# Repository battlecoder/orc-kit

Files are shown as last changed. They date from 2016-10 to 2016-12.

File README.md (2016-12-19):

# orc-kit
Open Source (and Hardware) Robotics Project.

Folder Content:
<ul>
<li><b>dist:</b> 3D models and vector patterns in "ready to use" formats (DXF and STL). Instructional sheet inside.</li>
<li><b>arduino:</b> Arduino libraries and example sketches for starters.</li>
<li><b>pcbs:</b> Eagle file and PNG render for the project custom circuit boards (Optional content)</li>
<li><b>vector-models:</b> "Source" files for the vector drawings and pieces (in SVG format)</li>
<li><b>3d pieces:</b> "Source" files for the 3D models (in SketchUp format)</li>
</ul>

For more information visit <a href="http://damnsoft.org/orc-kit">damnsoft.org/orc-kit</a>.

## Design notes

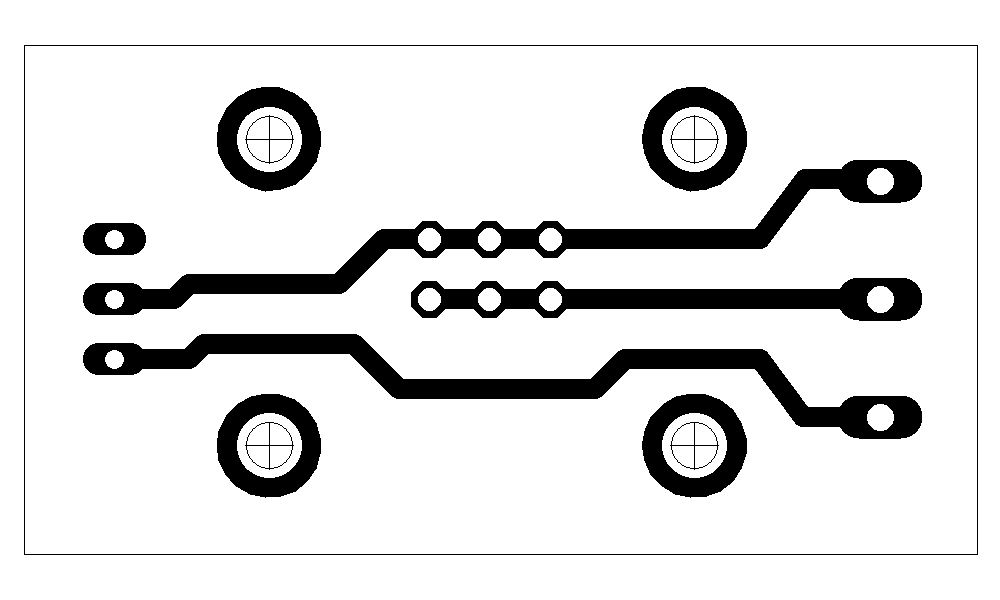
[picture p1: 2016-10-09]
pcbs/power_hub/power_hub.png

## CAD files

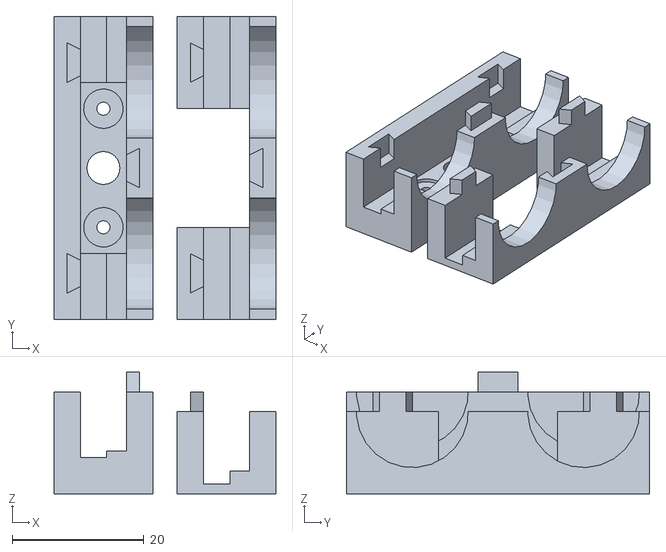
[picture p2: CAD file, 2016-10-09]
dist/3d pieces/ORC-KIT Sonar Mount (tight slanted tabs).stl
33.7 x 46.0 x 18.5

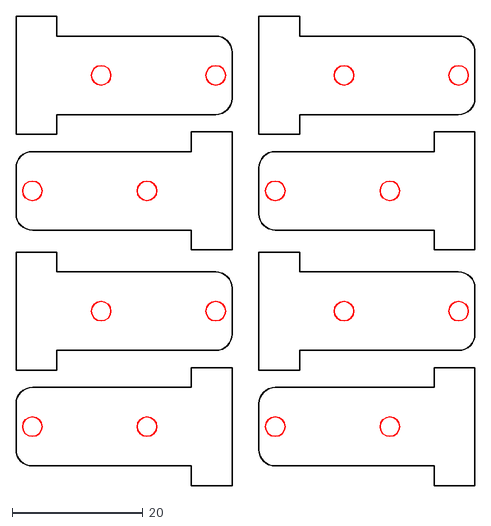
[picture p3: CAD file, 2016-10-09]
dist/lasercut/ORC-KIT Motor Mount set.dxf
70.1 x 71.6

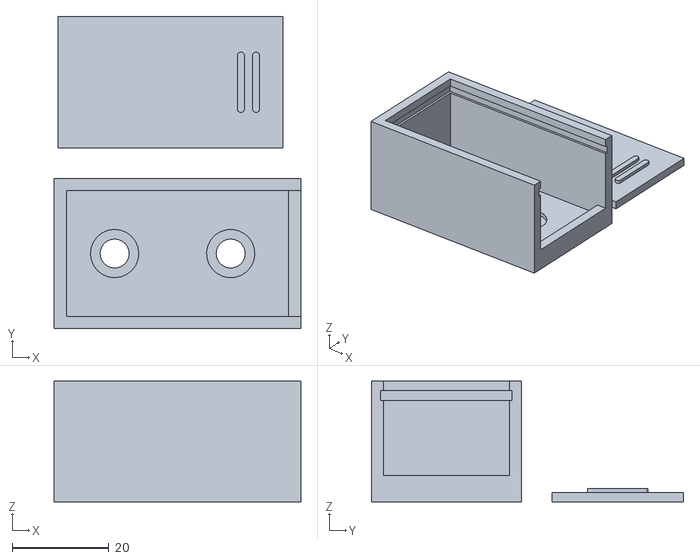
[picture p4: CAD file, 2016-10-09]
dist/3d pieces/ORC-KIT 9V Battery Holder.stl
51.0 x 64.5 x 25.0

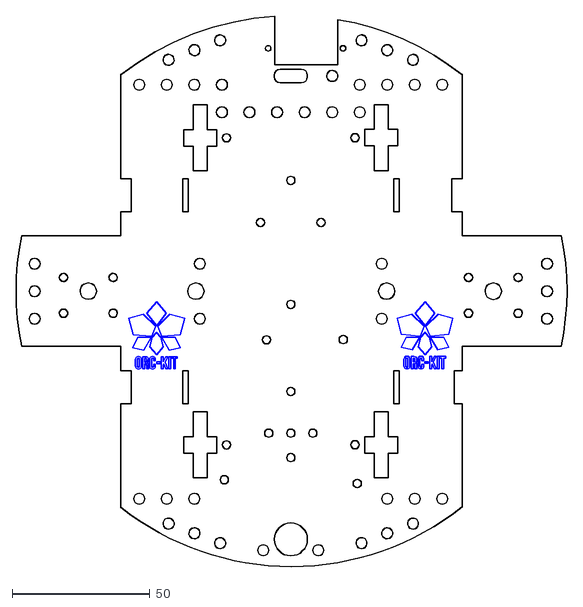
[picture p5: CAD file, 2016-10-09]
dist/lasercut/ORC-KIT Robot base.dxf
200.0 x 199.7

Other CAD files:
3d pieces/ORC-KIT 9V Battery Holder.skp
3d pieces/ORC-KIT Sonar Mount (tight slanted tabs).skp

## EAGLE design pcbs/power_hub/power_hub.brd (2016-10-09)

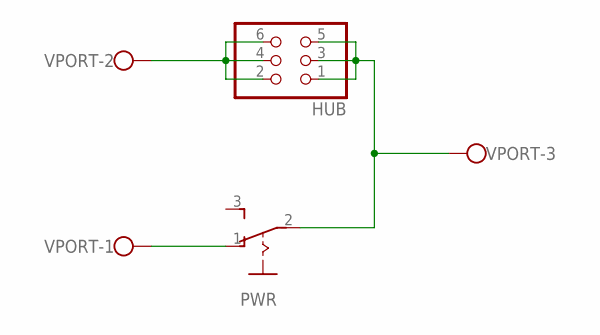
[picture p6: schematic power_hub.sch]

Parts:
HUB: PINHD-2X3; 2X03
PWR: M251
VPORT: W237-103

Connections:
unnamed: PWR.1 (O), VPORT.1
unnamed: HUB.1, HUB.3, HUB.5, PWR.2, VPORT.3
unnamed: HUB.2, HUB.4, HUB.6, VPORT.2

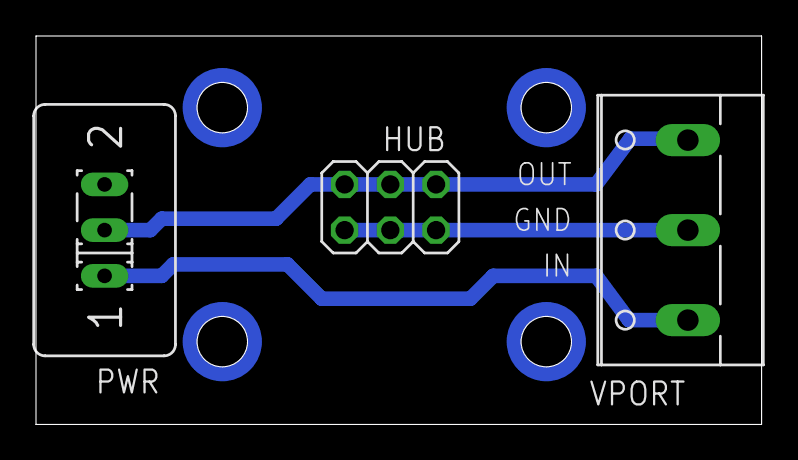
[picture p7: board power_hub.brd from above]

Board: 2 copper layers, 40.3 x 21.6 mm, 3 parts (0 on the bottom side), 3 nets.

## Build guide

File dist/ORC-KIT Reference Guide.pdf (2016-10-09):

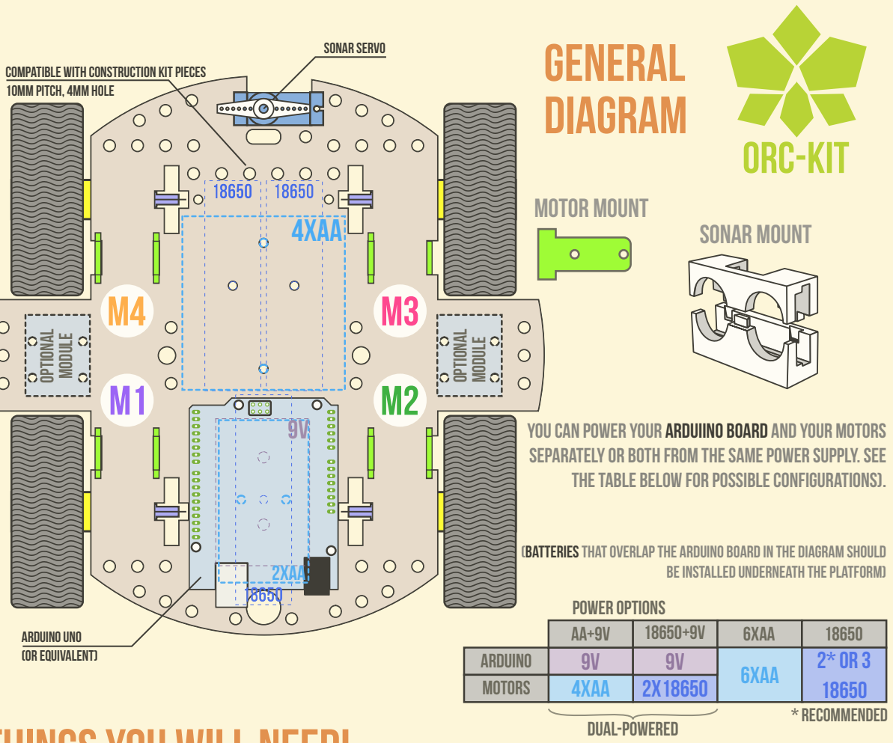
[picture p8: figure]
dual-powered; OPTIONAL; MODULE; Power OPTIONS; 6xAA; AA+9V 9V 4xAA; Arduino; Motors; * Recommended; 4xAA; 2xAA; GENERAL DIAGRAM; ARDuiNO UNO; (OR EQUIVALENT); sonar SERVO; COMPATIBLE WITH CONSTRUCTION kit pieces; 10MM PITCH, 4MM HOLE; Motor mount; BE INSTALLED UNDERNEATH THE PLATFORM); sonar mount

2016 orc-kit project by elias zacarias

1

2 12MM M2 SCREWS + BOLTS (FOR THE SONAR)

8 ORC-KIT MOTOR MOUNTS (ALSO LASER-CUT) OPTIONAL MODULE

FROM THE ORC-KIT PROJECT REPOSITORY

# things you will need!

STANDARD STUFF

1 ORC-KIT ROBOT BASE (LASER-CUT)

1 sonar mount (3d printed)
1 power hub board (optional. SEE PAGE 2)

1 ARDUINO UNO OR SIMILAR BOARD

4 HOBBY DC MOTORS WITH TIRES (THEY COME IN 48:1 AND 120:1 GEAR RATIOS)

1 ADAFRUIT MOTOR SHIELD OR 2X DUAL H-BRIDGES TO DRIVE THE MOTORS (*) 1 hc-sr04 or similar ultrasonic RANGEFINDER
1 sg90 MICROSERVO
BATTERIES & HOLDERS (DEPENDING ON YOUR CHOSEN power CONFIGURATION) PCB SPACERS/STANDOFFS AND THEIR RESPECTIVE M3 SCREWS AND BOLTs
1 hc-06 BLUETOOTH MODULE (optional. to be used with the bt control app!)

(*) the spots LABELED "OPTIONAL MODULE" IN THE DIAGRAM can hold in place TWO L9110S (OR SIMILAR) H-BRIDGES for shield-less builds. IF A DEDICATED ARDUINO SHIELD IS USED, HOWEVER, YOU CAN INSTALL SIMPLE CIRCUITS THERE, LIKE a BT/RADIO TRANSCEIVER, ORC KIT'S power hub, EXTRA SENSORS, ETC.

YOU CAN POWER YOUR ARDUIINO BOARD AND YOUR MOTORS SEPARATELY OR BOTH FROM THE SAME POWER SUPPLY. SEE THE TABLE below FOR POSSIBLE CONFIGURATIONS).

(BATTERIES THAT OVERLAP THE ARDUINO BOARD IN THE DIAGRAM SHOULD

1 TOGGLE switch (optional. not needed if using a power hub WITH SWITCH)

8 25MM (Or 30mm) m3 screws + boltS (for the motor MOUNTs)

1 orc-kit 9v battery holder (3d printed. required ONLY FOR dual power config.)

# construction process overview

SOLDER WIRES TO THE MOTORS AND INSTALL THEM UNDER THE BASE USING THE MOTOR MOUNTS.

WRITE AN ARDUINO SKETCH TO check THAT EVERYTHING WORKS!
(IF YOU USED THE COMPONENTS RECOMMENDED HERE YOU CAN USE THE SKETCHES FROM THE ORC-KIT PROJECT REPOSITORY)

Screw THE BATTERY HOLDERS REQUIRED BY YOUR SELECTED POWER CONFIGURATION IN PLACE.

INSTALL THE sonar SERVO (plus SERVO ARM) AND attach tHE SONAR MOUNT to it.

MOUNT and wire THE ELECTRONICS: ARDUINO, RANGE-FINDER, SHIELDS, etc.

2

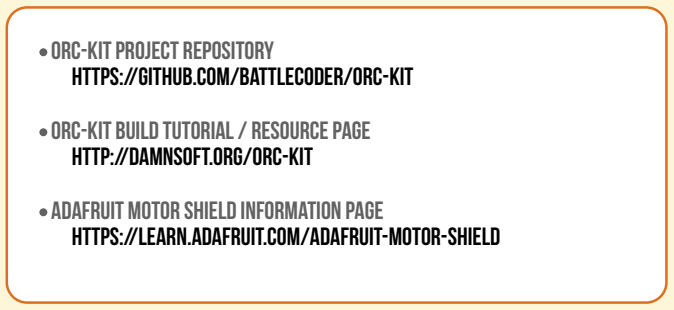
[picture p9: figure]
ADAFRUIT MOTOR SHIELD INFORMATION PAGE; ORC-KIT BUILD TUTORIAL / RESOURCE PAGE http://damnsoft.org/orc-kit; https://learn.adafruit.com/adafruit-motor-shield; ORC-KIT PROJECT REPOSITORY https://github.com/battlecoder/orc-kit

2016 orc-kit project by elias zacarias

motor 2

M1

M2 +m gnd

m3

m4

SERVO_1
servo_2
- + S

+5V
GND
A0-5

pwr

GND GND

+v

## 4 X AA 2 XAA

18650

18650

- or -

## batteries

aa (X6) or 18650 (X2)
recommended *

* other configurations are possible. CHECK power confiG. TABLE IN PAGE 1.

## ORC-KIT'S power hub

## hc-sr04

ultrasoNIC rangefinder

## sonar servo

(sonar mount goes here)

### ADAFRUIT MOTOR SHIELD

(Or compatible)

# connectIon diagram

# (using an adafruit motor shield or equivalent)

if you want to power motors and arduino independently, REMOVE THE "PWR" JUMPER FROM THe motor SHIELD, and connect only THE batteries that will power the motors. then INSTALL A 9V BATTERY under the body of the robot and connect it to the arduino board VIA a standard 2.1MM barrel plug.

GND

TRIGGER

ECHO

VCC

motor 1

motor 4

motor 3

## switch

(optional)

# USEFUL LINKS:

-oR-

hc-06

Bluetooth module (optional)

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
ARDUINO PIN

only required for BT communication and use of the orc-kit control app

# SOFTWARE:

In the project repository you will find 2 arduino sketches, designed to work with the components shown here:

TEST: ACTIVATES the motors so they MOVE "forward", AND CENTERS THE SONAR servo, REPORTING VIA SERIAL INTERFACE THE MEASURED DISTANCE.
USe this sketch TO MAKE SURE EVERYTHING IS WIRED CORRECTLY and as a base for your own code!

BT-REMOTE: A simple serial remote control scheme to be used with the orc-kit remote control app (android). requires the hc-06 bluetooth module.

DUAL POWERED CONFIGURATION

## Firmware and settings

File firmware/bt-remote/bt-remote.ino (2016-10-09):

#include <Servo.h>
#include "libraries/ORC_sonar/ORC_sonar.h"
#include "libraries/ORC_radioctl/ORC_radioctl.h"
#include "libraries/ORC_motorshield/ORC_motorshield.h"

// Extra hardware pin assignments ------------------------
#define SONAR_TRIGGER_PIN   A0
#define SONAR_ECHO_PIN      A1

// Other constants ---------------------------------------
#define MIN_SPEED          96  // Values smaller than this barely move the motors with my batteries. You can try with other values though.
#define MAX_SPEED          255  // This is the max speed supported by the framework. Don't change.

// Global variables and objects --------------------------
Sonar       sonar1(SONAR_TRIGGER_PIN, SONAR_ECHO_PIN);
byte        currentLeftSpeed;
byte        currentRightSpeed;
Motor_Cmd   currentLeftCmd;
Motor_Cmd   currentRightCmd;
// ###############################################################
// ##                                                           ##
// ##   H I G H - L E V E L   S O N A R   F U N C T I O N S     ##
// ##                                                           ##
// ###############################################################
// moveSonarToAngle --------------------------------------
//  Moves the sonar servo to a given angle.
//  Make sure the sonar servo is connected to servo_1 in
//  the Shield.
// -------------------------------------------------------
void moveSonarToAngle (byte angle) {
  MotorShield.servo1.write (angle);
}

// readSonarInCms ----------------------------------------
//  obtains the current sonar reading in cms.
// -------------------------------------------------------
int readSonarInCms () {
  return sonar1.readSonarInCms();
}

// readSonarInInches -------------------------------------
//  obtains the current sonar reading in inches.
// -------------------------------------------------------
int readSonarInInches () {
  return sonar1.readSonarInInches();
}

// ###############################################################
// ##                                                           ##
// ##   H I G H - L E V E L   M O T O R   F U N C T I O N S     ##
// ##                                                           ##
// ###############################################################
// setRightSideSpeed -------------------------------------
//  Changes the speed of the RIGHT-side motors.
// -------------------------------------------------------
void setRightSideSpeed (byte speed) {
  if (currentRightSpeed == speed) return;
  MotorShield.setMotorSpeed(MOTOR_2, speed);
  MotorShield.setMotorSpeed(MOTOR_3, speed);
  currentRightSpeed = speed;
}

// setLeftSideSpeed --------------------------------------
//  Changes the speed of the LEFT-side motors.
// -------------------------------------------------------
void setLeftSideSpeed (byte speed) {
  if (currentLeftSpeed == speed) return;
  MotorShield.setMotorSpeed(MOTOR_1, speed);
  MotorShield.setMotorSpeed(MOTOR_4, speed);
  currentLeftSpeed = speed;
}

// setRightSideMovement ----------------------------------
//  Sends a given command to the RIGHT-side motors.
//  Available commands (declared in ORC_motorshield.h)
//  are:
//    MOTOR_STOP
//    MOTOR_FWD
//    MOTOR_BACK
// -------------------------------------------------------
void setRightSideMovement (Motor_Cmd command) {
  if (currentRightCmd == command) return;
  MotorShield.setMotorCommand(MOTOR_2, command);
  MotorShield.setMotorCommand(MOTOR_3, command);
  currentRightCmd = command;
}

// setLeftSideMovement -----------------------------------
//  Sends a given command to the LEFT-side motors.
//  Available commands (declared in ORC_motorshield.h)
//  are:
//    MOTOR_STOP
//    MOTOR_FWD
//    MOTOR_BACK
// -------------------------------------------------------
void setLeftSideMovement (Motor_Cmd command) {
  if (currentLeftCmd == command) return;
  MotorShield.setMotorCommand(MOTOR_1, command);
  MotorShield.setMotorCommand(MOTOR_4, command);
  currentLeftCmd = command;
}

// spinRight ---------------------------------------------
// Spins clockwise at a given speed.
// -------------------------------------------------------
void spinRight (byte spinSpeed) {
  setLeftSideMovement (MOTOR_FWD);
  setRightSideMovement (MOTOR_BACK);
  setRightSideSpeed (spinSpeed);
  setLeftSideSpeed (spinSpeed);
}

// spinLeft ----------------------------------------------
// Spins counter-clockwise at a given speed.
// -------------------------------------------------------
void spinLeft (byte spinSpeed) {
  setLeftSideMovement (MOTOR_BACK);
  setRightSideMovement (MOTOR_FWD);
  setRightSideSpeed (spinSpeed);
  setLeftSideSpeed (spinSpeed);
}

// motorsOff ---------------------------------------------
// Stops both motors
// -------------------------------------------------------
void motorsOff () {
  setLeftSideMovement (MOTOR_STOP);
  setRightSideMovement (MOTOR_STOP);
}

// reverse -----------------------------------------------
// Drives in reverse. Both motors can be set to spin at
// different speeds.
// -------------------------------------------------------
void reverse (byte leftSpeed, byte rightSpeed) {
  setLeftSideMovement (MOTOR_BACK);
  setRightSideMovement (MOTOR_BACK);
  setLeftSideSpeed (leftSpeed);
  setRightSideSpeed (rightSpeed);
}


// forward -----------------------------------------------
// Drives forward. Both motors can be set to spin at
// different speeds.
// -------------------------------------------------------
void forward (byte leftSpeed, byte rightSpeed) {
  setLeftSideMovement (MOTOR_FWD);
  setRightSideMovement (MOTOR_FWD);
  setLeftSideSpeed (leftSpeed);
  setRightSideSpeed (rightSpeed);
}

// ###############################################################
// ##                                                           ##
// ##         A R D U I N O   E N T R Y   P O I N T S           ##
// ##                                                           ##
// ###############################################################
// setup -------------------------------------------------
//  When the Arduino "boots", this function will be called
//  once, so this is the perfect place to configure stuff before
//  we do anything. After this procedure ends, Arduino
//  will start running our loop() function until the board
//  is turned off (or resets).
// -------------------------------------------------------
void setup() {
  // Serial radio link
  ORCRadioControl.begin(9600);
  
  // "Attach" servos, so we can use them.
  MotorShield.attachServos();

  // Default sonar head position:
  moveSonarToAngle (90);
}

// loop --------------------------------------------------
//  This procedure be executed for as long as the Arduino
//  board is powered.
// -------------------------------------------------------
void loop(){
  // readAndParse() returns true when a new data packet has been processed and we can query the
  // new values for X, Y and buttons. We will use this event to update what our motors are doing.
  if (ORCRadioControl.readAndParse()){
    int xAxis    = ORCRadioControl.getCurrentX();
    int throttle  = ORCRadioControl.getCurrentY();
    byte speed, speed2;

    // When both sticks are centered we want the robot to stop ~~~~~~~~~~~~~~~~~~~~~~~~~
    if (throttle == 0 && xAxis == 0){
      motorsOff();
    }else {
      // If only the throttle stick is centered we want to spin in place  ~~~~~~~~~~~~~~
      if (throttle == 0){
        // Speed will be obtained directly from the horizontal stick.
        speed = map(abs(xAxis), 0, 7, MIN_SPEED, MAX_SPEED);
        if (xAxis < 0){
          spinLeft (speed);
        }else {
          spinRight (speed);
        }

      }else {
        // This section will deal with the general motion case, which normally involves moving forwards or backwards
        // and steering either right or left (to some extent) at the same time.
        // Thus, we will need to compute the speed for the "dominant" (i.e: faster) and "non-dominant" (i.e: slower) side of
        // the robot as follows:
        // Dominant side will get its speed directly from the throtle axis:
        speed = map (abs(throttle), 0, 7, MIN_SPEED, MAX_SPEED);
        // Non-dominant side will move at a fraction of the dominant side speed, proportional to the xAxis value.
        // Note that for xAxis = 0 (centered X stick) both speeds will be equal, so there's no need to treat xAxis = 0
        // as an special case.
        speed2 = map (abs(xAxis), 0, 7, speed, 0); 

        // If the throttle stick is a negative number then we want to go reverse ~~~~~~~~~
        if (throttle < 0) {
          // Which side is dominant depends on whether we are pushing the X stick left or right
          if (xAxis < 0) {
            reverse (speed, speed2);
          }else {
            reverse (speed2, speed);
          }

        // Otherwise we want to go forward ~~~~~~~~~~~~~~~~~~~~~~~~~~~~~~~~~~~~~~~~~~~~~~~
        }else {
          // Let's check what the sonar says before moving forward. If there's an obstacle near
          // we actually want to stop.
          //if (readSonarInCms() < 25){
          if (false){
            motorsOff();

          // Which side is dominant depends on whether we are pushing the X stick left or right
          }else if (xAxis < 0) {
            forward (speed2, speed);
          }else {
            forward (speed, speed2);
          }
        }
      }
    }
    ORCRadioControl.send(ORCRadioControl.getCurrentX(), DEC);
    ORCRadioControl.send(' ');
    ORCRadioControl.send(ORCRadioControl.getCurrentY(), DEC);
    ORCRadioControl.send(' ');
    ORCRadioControl.sendDataEnd();
  }
}

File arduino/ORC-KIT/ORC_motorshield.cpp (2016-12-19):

// ###############################################################
// ##  ORC_motorshield.cpp:                                     ##
// ##  ----------------------------                             ##
// ##  Code for ORC-KIT's driver for Adafruit's motorshield,    ##
// ##                                                           ##
// ## Part of the ORC-Kit project.                              ##
// ##                                                           ##
// ## History:                                                  ##
// ##  ----------------------------                             ##
// ## - 2016/12/19 Elias Zacarias                               ##
// ##     Minor adaptations to create a version compatible with ##
// ##     standalone H-bridges.                                 ##
// ##  ----------------------------                             ##
// ## - 2016/10/09 Elias Zacarias                               ##
// ##     Released on GitHub.                                   ##
// ##  ----------------------------                             ##
// ## - 2016/04/10 Elias Zacarias                               ##
// ##     First released version.                               ##
// ##  ----------------------------                             ##
// ##                                                           ##
// ###############################################################
#include "ORC_motorshield.h"

// ###############################################################
// ##                                                           ##
// ##               L O C A L  C O N S T A N T S                ##
// ##                                                           ##
// ###############################################################
// Bit positions of motor flags in the motor register
#define MOTOR1_A 2
#define MOTOR1_B 3
#define MOTOR2_A 1
#define MOTOR2_B 4
#define MOTOR3_A 5
#define MOTOR3_B 7
#define MOTOR4_A 0
#define MOTOR4_B 6

// ###############################################################
// ##                                                           ##
// ##                  S T A T I C   D A T A                    ##
// ##                                                           ##
// ###############################################################
static byte    motorData;
static byte    motorboard_initd = 0;

// ###############################################################
// ##                                                           ##
// ##                 C L A S S   M E T H O D S                 ##
// ##                                                           ##
// ###############################################################
void MotorShieldDrv::setMotorSpeed (Motor_Index motor, byte mspeed){
  switch (motor){
    case MOTOR_1:
      analogWrite(MTRCTL_M1PWM, mspeed);
      break;
    case MOTOR_2:
      analogWrite(MTRCTL_M2PWM, mspeed);
      break;
    case MOTOR_3:
      analogWrite(MTRCTL_M3PWM, mspeed);
      break;
    case MOTOR_4:
      analogWrite(MTRCTL_M4PWM, mspeed);
      break;
  }
}

void MotorShieldDrv::setMotorCommand (Motor_Index motor, Motor_Cmd command){
  boolean aVal = LOW;
  boolean bVal = LOW;

  if (command == MOTOR_FWD) {
    aVal = HIGH;
    bVal = LOW;
  } else if (command == MOTOR_BACK) {
    aVal = LOW;
    bVal = HIGH;
  }

  bitWrite (PORTD, 7, LOW); //Enable PIN

  switch (motor) {
    case MOTOR_1:
      bitWrite (motorData, MOTOR1_A, aVal);
      bitWrite (motorData, MOTOR1_B, bVal);
      break;
    case MOTOR_2:
      bitWrite (motorData, MOTOR2_A, aVal);
      bitWrite (motorData, MOTOR2_B, bVal);
      break;
    case MOTOR_3:
      bitWrite (motorData, MOTOR3_A, aVal);
      bitWrite (motorData, MOTOR3_B, bVal);
      break;
    case MOTOR_4:
      bitWrite (motorData, MOTOR4_A, aVal);
      bitWrite (motorData, MOTOR4_B, bVal);
      break;
    default:
      return;
  }

  digitalWrite (MTRCTL_LATCH, LOW);
  shiftOut(MTRCTL_DATA, MTRCTL_CLK, MSBFIRST, motorData);
  digitalWrite (MTRCTL_LATCH, HIGH);
}

void MotorShieldDrv::attachServos(){
  servo1.attach (MTRCTL_SERVO1);
  servo2.attach (MTRCTL_SERVO2);
}


// Init routine
void MotorShieldDrv::init() {
  if (motorboard_initd) return;
  motorboard_initd = 1;

  pinMode (MTRCTL_LATCH,   OUTPUT);
  pinMode (MTRCTL_ENABLE,  OUTPUT);
  pinMode (MTRCTL_DATA,    OUTPUT);
  pinMode (MTRCTL_CLK,     OUTPUT);
  
  pinMode (MTRCTL_M1PWM,   OUTPUT);
  pinMode (MTRCTL_M2PWM,   OUTPUT);
  pinMode (MTRCTL_M3PWM,   OUTPUT);
  pinMode (MTRCTL_M4PWM,   OUTPUT);

  setMotorCommand(MOTOR_1, MOTOR_STOP);
  setMotorCommand(MOTOR_2, MOTOR_STOP);
  setMotorCommand(MOTOR_3, MOTOR_STOP);
  setMotorCommand(MOTOR_4, MOTOR_STOP);

  setMotorSpeed (MOTOR_1, 255);
  setMotorSpeed (MOTOR_2, 255);
  setMotorSpeed (MOTOR_3, 255);
  setMotorSpeed (MOTOR_4, 255);
}

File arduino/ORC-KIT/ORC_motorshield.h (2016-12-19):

// ###############################################################
// ##  ORC_motorshield.h:                                       ##
// ##  ----------------------------                             ##
// ##  A very simple driver for Adafruit's Motorshield (or      ##
// ##  clone) boards and standard H-bridges. This code controls ##
// ##  4 DC motor outputs and 2 servos.                         ##
// ##                                                           ##
// ##  More info about the board at:                            ##
// ##    https://learn.adafruit.com/adafruit-motor-shield       ##
// ##                                                           ##
// ## Part of the ORC-Kit project.                              ##
// ##                                                           ##
// ## History:                                                  ##
// ##  ----------------------------                             ##
// ## - 2016/12/19 Elias Zacarias                               ##
// ##     Minor adaptations to create a version compatible with ##
// ##     standalone H-bridges.                                 ##
// ##  ----------------------------                             ##
// ## - 2016/10/09 Elias Zacarias                               ##
// ##     Released on GitHub.                                   ##
// ##  ----------------------------                             ##
// ## - 2016/04/10 Elias Zacarias                               ##
// ##     First released version.                               ##
// ##  ----------------------------                             ##
// ##                                                           ##
// ###############################################################
#ifndef __ORC_MOTORSHIELD_H
#define __ORC_MOTORSHIELD_H

#include "Arduino.h"
#include "ORC_motorbase.h"
#include "Servo.h"

// "Common" alias
#define ORCKITMotorController MotorShieldDrv

// Board pinout -------------------------------
// Adafruit's Motorshield (v1) driver
// This configuration should not be changed!
#define MTRCTL_M1PWM    11
#define MTRCTL_M2PWM    3
#define MTRCTL_M3PWM    6
#define MTRCTL_M4PWM    5
#define MTRCTL_LATCH    12
#define MTRCTL_CLK      4
#define MTRCTL_ENABLE   7
#define MTRCTL_DATA     8

#define MTRCTL_SERVO1   10
#define MTRCTL_SERVO2   9

// Class Definition ---------------------------
class MotorShieldDrv {
public:
  Servo servo1;
  Servo servo2;  

  void attachServos();
  void init();
  void setMotorSpeed (Motor_Index motor, byte mspeed);
  void setMotorCommand (Motor_Index motor, Motor_Cmd command);
  
};

#endif

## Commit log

2016-10-09 All files pushed to repository
    [ORC-KIT 9V Battery Holder.skp, ORC-KIT 9V Battery Holder.stl, ORC-KIT Motor Mount set.dxf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]
2016-10-15 Updated model reference with correct base frame thickness (4mm)
2016-12-19 Refactored the Arduino code so it can be imported as a library from the IDE. Added an HBridge driver fully compatible with the previous Motorshield controller. Modified the Radiocontrol class and exa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
    [ORC_hbridgedrv.cpp, ORC_motorshield.cpp, ORC_motorshield.h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]
